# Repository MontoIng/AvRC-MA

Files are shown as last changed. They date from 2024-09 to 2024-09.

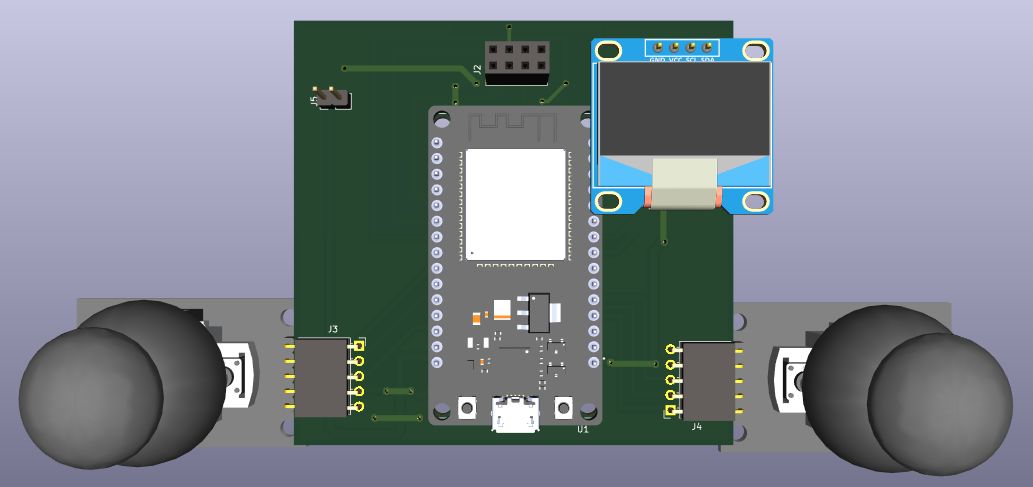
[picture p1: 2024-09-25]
PCBs/Imágenes (KiCad)/Control/Diseño PCB Final (3D - Lado 1).png

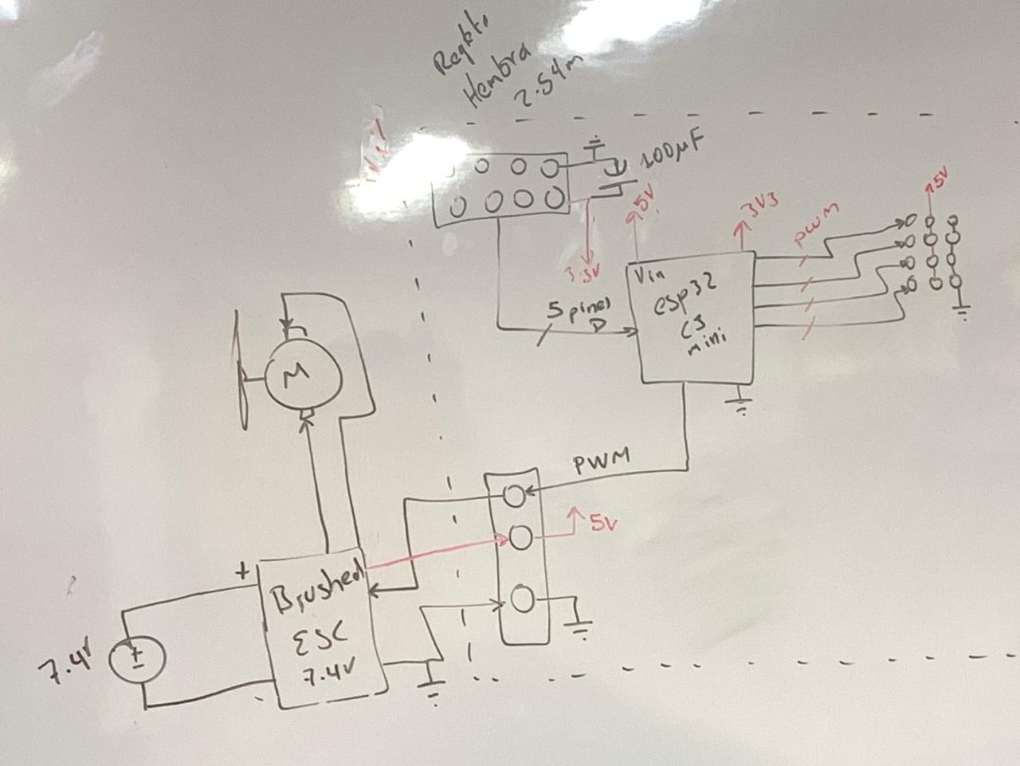
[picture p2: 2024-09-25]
Diseño (muestras)/Diseño prototipado.jpeg

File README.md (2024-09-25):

# AvRC-MA
Avión RC - Monitoreo Ambiental
- En este proyecto se realizó un avión RC (Radio - Control) capaz de tomar datos de temperatura, presión y humedad.
(Santiago Montoya M.)
- Se subió cada codificación usada y creada en la realización del proyecto.
  Siendo asi estos: - Código del control.
                    - Código del Avión.
                    - Código para calibrar el motor.
                    - Librería BME280.
- Se organizó por carpeta los códigos, diseños (muestras - evidencias), documentos y PCBs.
- Se subieron los documentos respectivos a las carpetas.

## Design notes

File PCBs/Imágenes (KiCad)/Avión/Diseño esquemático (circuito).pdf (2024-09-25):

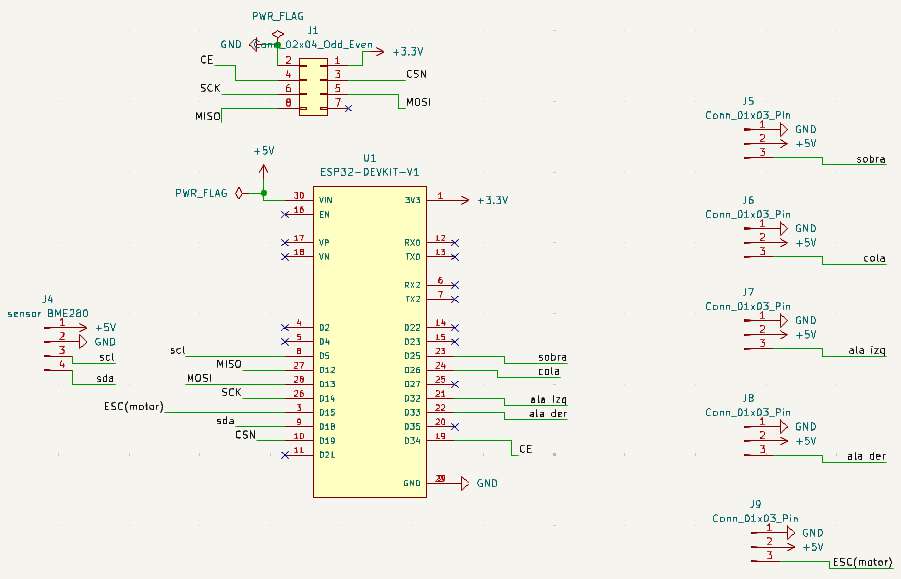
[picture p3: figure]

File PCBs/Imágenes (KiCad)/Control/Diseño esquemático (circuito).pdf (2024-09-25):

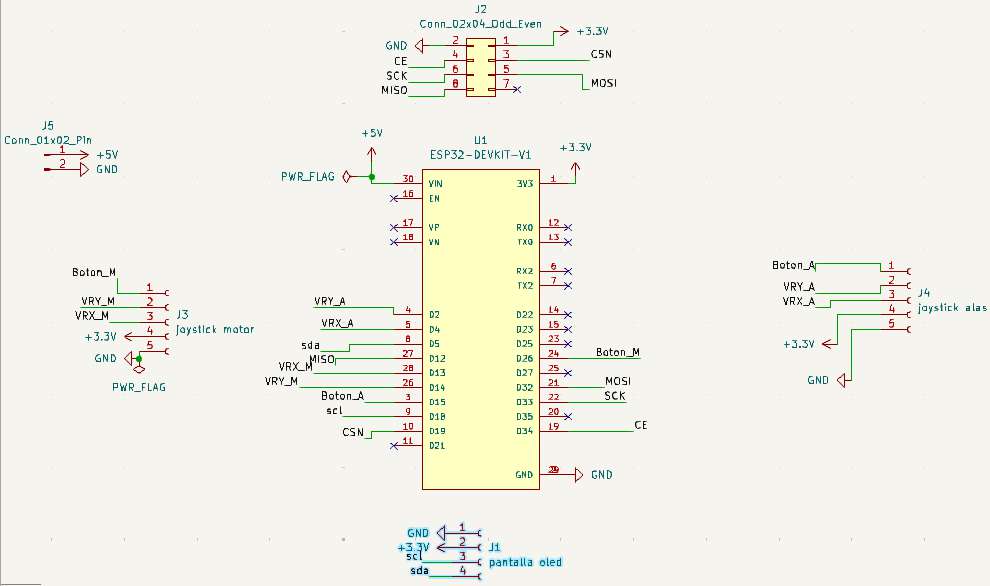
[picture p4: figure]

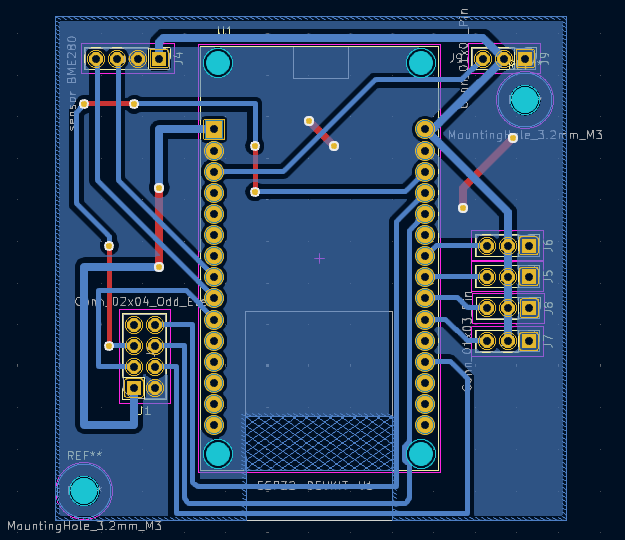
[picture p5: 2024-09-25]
PCBs/Imágenes (KiCad)/Avión/Diseño de PCB (ruteo).png

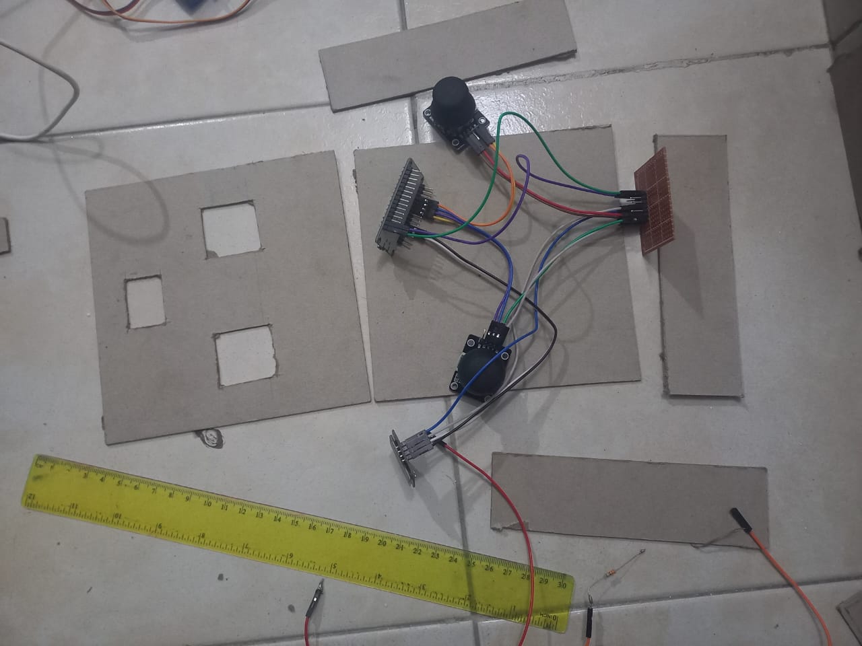
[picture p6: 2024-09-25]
Diseño (muestras)/Diseño (corte).jpeg

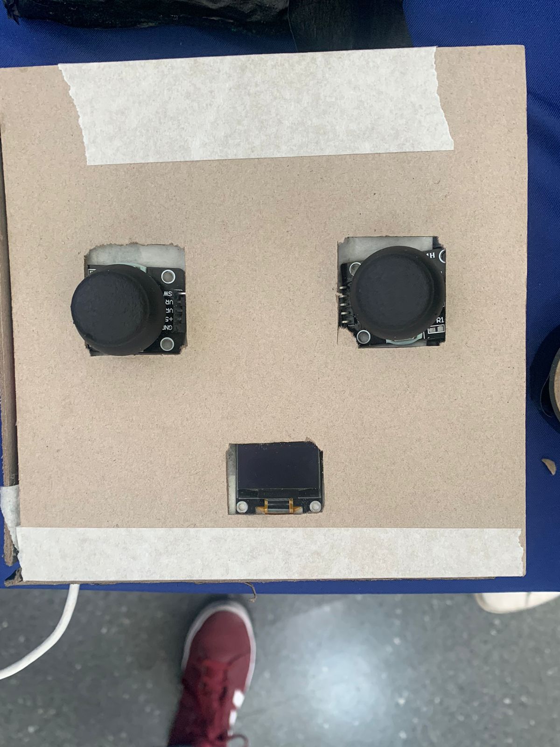
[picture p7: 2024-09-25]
Diseño (muestras)/Diseño control.jpeg

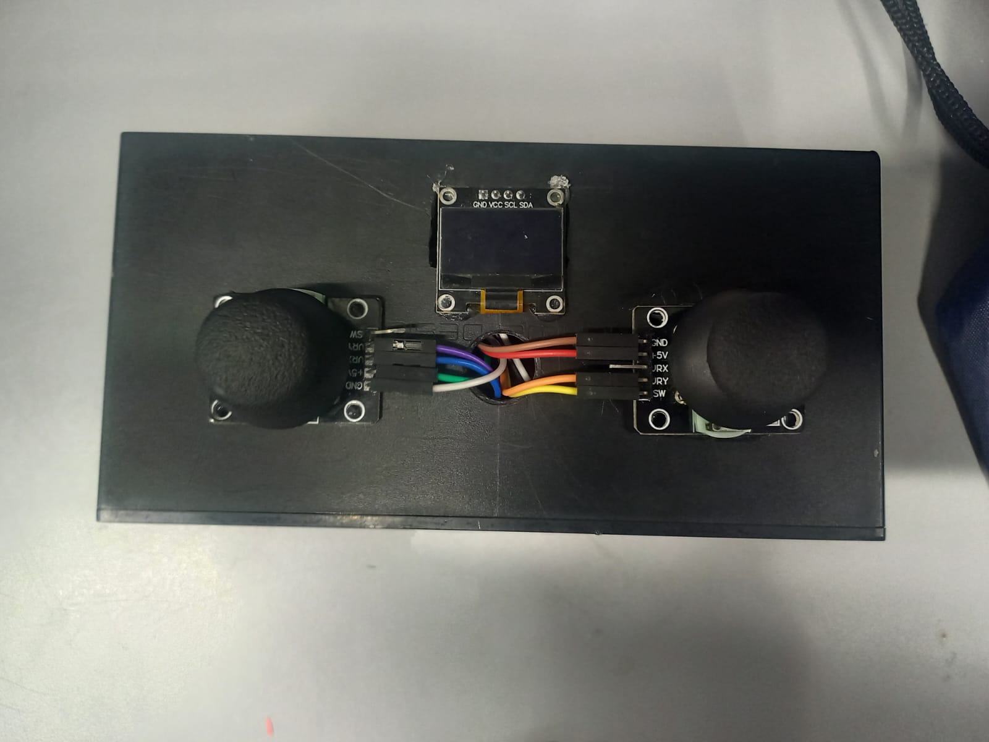
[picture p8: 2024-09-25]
Diseño (muestras)/Diseño control (final).jpeg

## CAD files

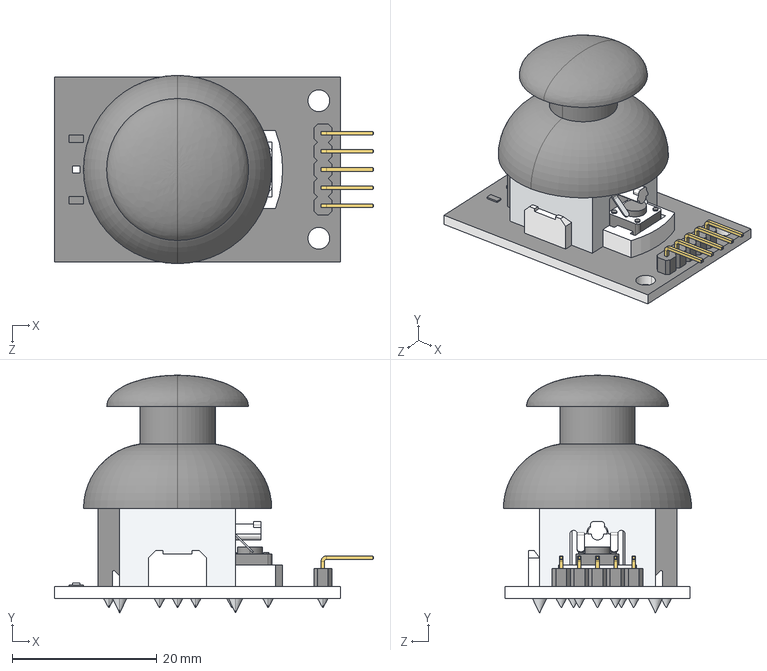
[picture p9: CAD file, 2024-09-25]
PCBs/avion/pcb control/librerias/joystick-module-3.snapshot.1/Joystick.STEP
44.0 x 32.8 x 26.0 mm

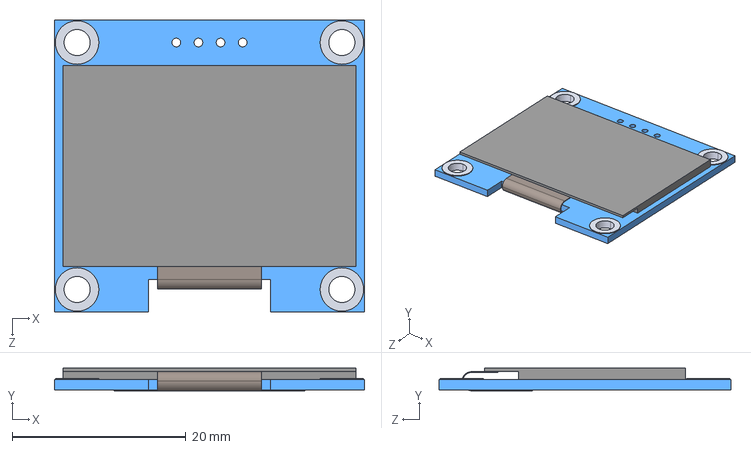
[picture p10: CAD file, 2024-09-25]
PCBs/avion/pcb control/librerias/oled.STEP
35.6 x 2.60 x 33.6 mm

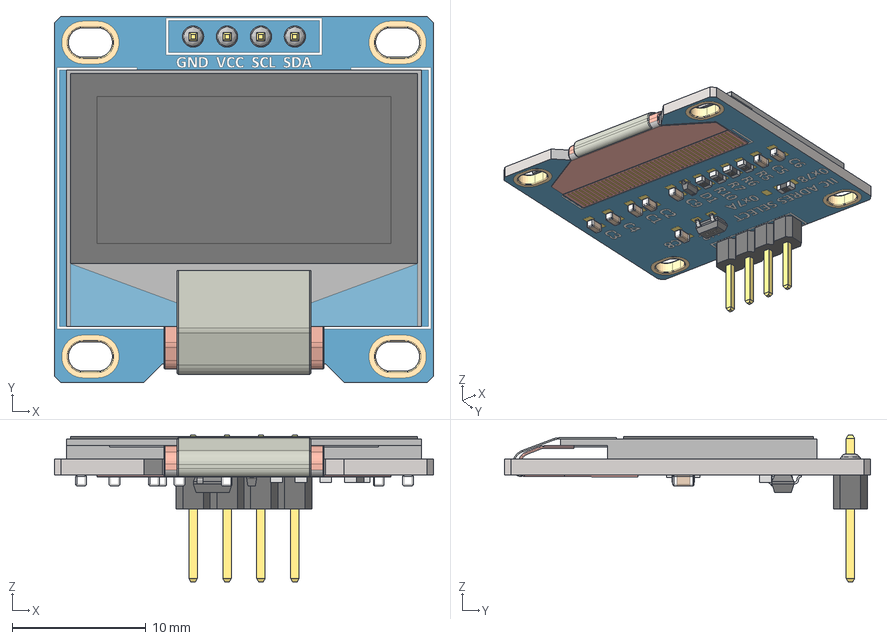
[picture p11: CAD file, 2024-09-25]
PCBs/avion/pcb control/librerias/Pantalla OLED 0.96'' 128x64.stp
28.4 x 27.4 x 11.0 mm
SOT-23_TOR
RES_CR16_MTK_1 x 4
RES_CR16_MTK
SOD323F_DIO

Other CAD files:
PCBs/avion/pcb control/librerias/joystick-module-3.snapshot.1/Joystick.SLDPRT

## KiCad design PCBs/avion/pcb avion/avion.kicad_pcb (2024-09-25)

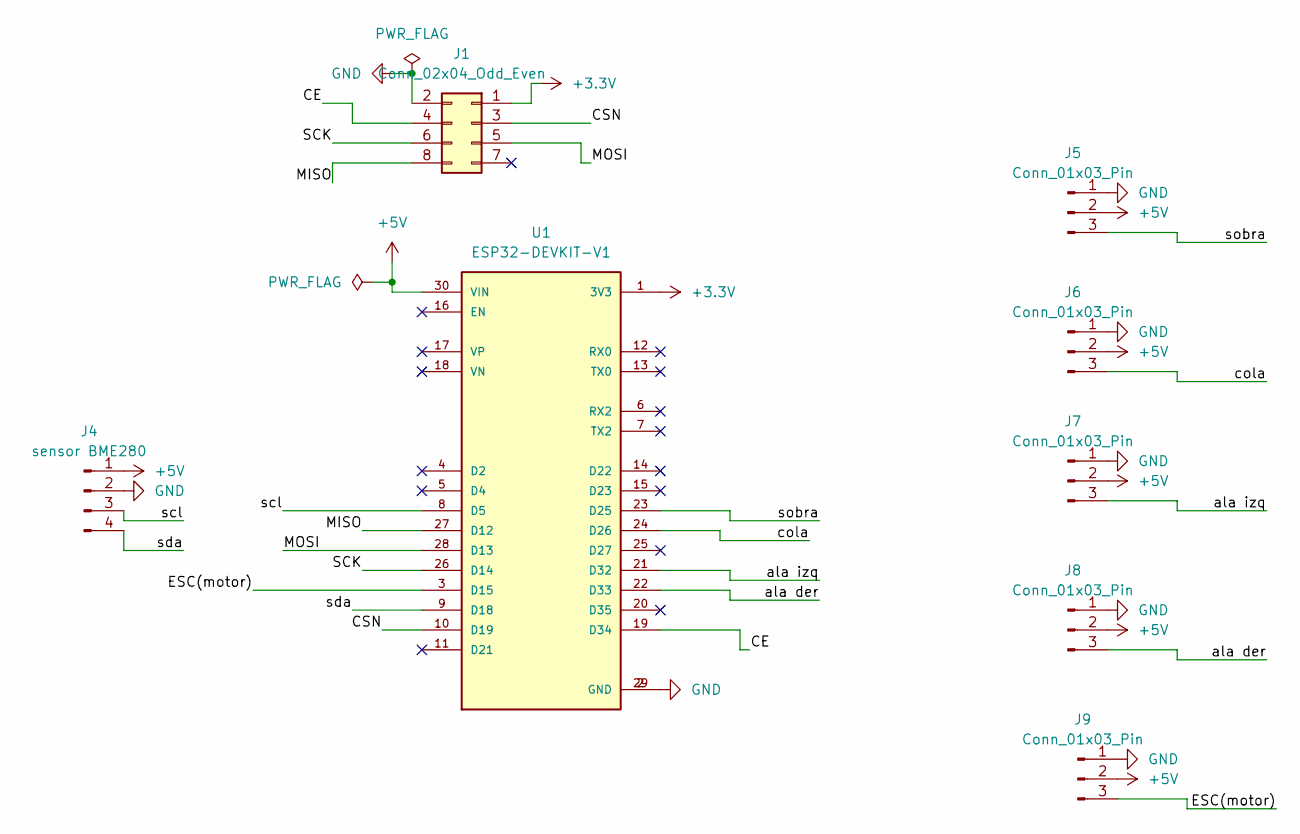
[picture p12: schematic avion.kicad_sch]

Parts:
J1: Conn_02x04_Odd_Even; PinSocket_2x04_P2.54mm_Vertical
J4: sensor BME280; PinHeader_1x04_P2.54mm_Vertical
J5, J6, J7, J8, J9: Conn_01x03_Pin; PinHeader_1x03_P2.54mm_Vertical
U1: ESP32-DEVKIT-V1; MODULE_ESP32_DEVKIT_V1; PARTREV N/A

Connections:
+3.3V: J1.1, U1.1 (3V3)
+5V: J4.1, J5.2, J6.2, J7.2, J8.2, J9.2, U1.30 (VIN)
/CE: J1.4, U1.19 (D34)
/CSN: J1.3, U1.10 (D19)
/ESC(motor): J9.3, U1.3 (D15)
/MISO: J1.8, U1.27 (D12)
/MOSI: J1.5, U1.28 (D13)
/SCK: J1.6, U1.26 (D14)
/ala der: J8.3, U1.22 (D33)
/ala izq: J7.3, U1.21 (D32)
/cola: J6.3, U1.24 (D26)
/scl: J4.3, U1.8 (D5)
/sda: J4.4, U1.9 (D18)
/sobra: J5.3, U1.23 (D25)
GND: J1.2, J4.2, J5.1, J6.1, J7.1, J8.1, J9.1, U1.2 (GND), U1.29 (GND)

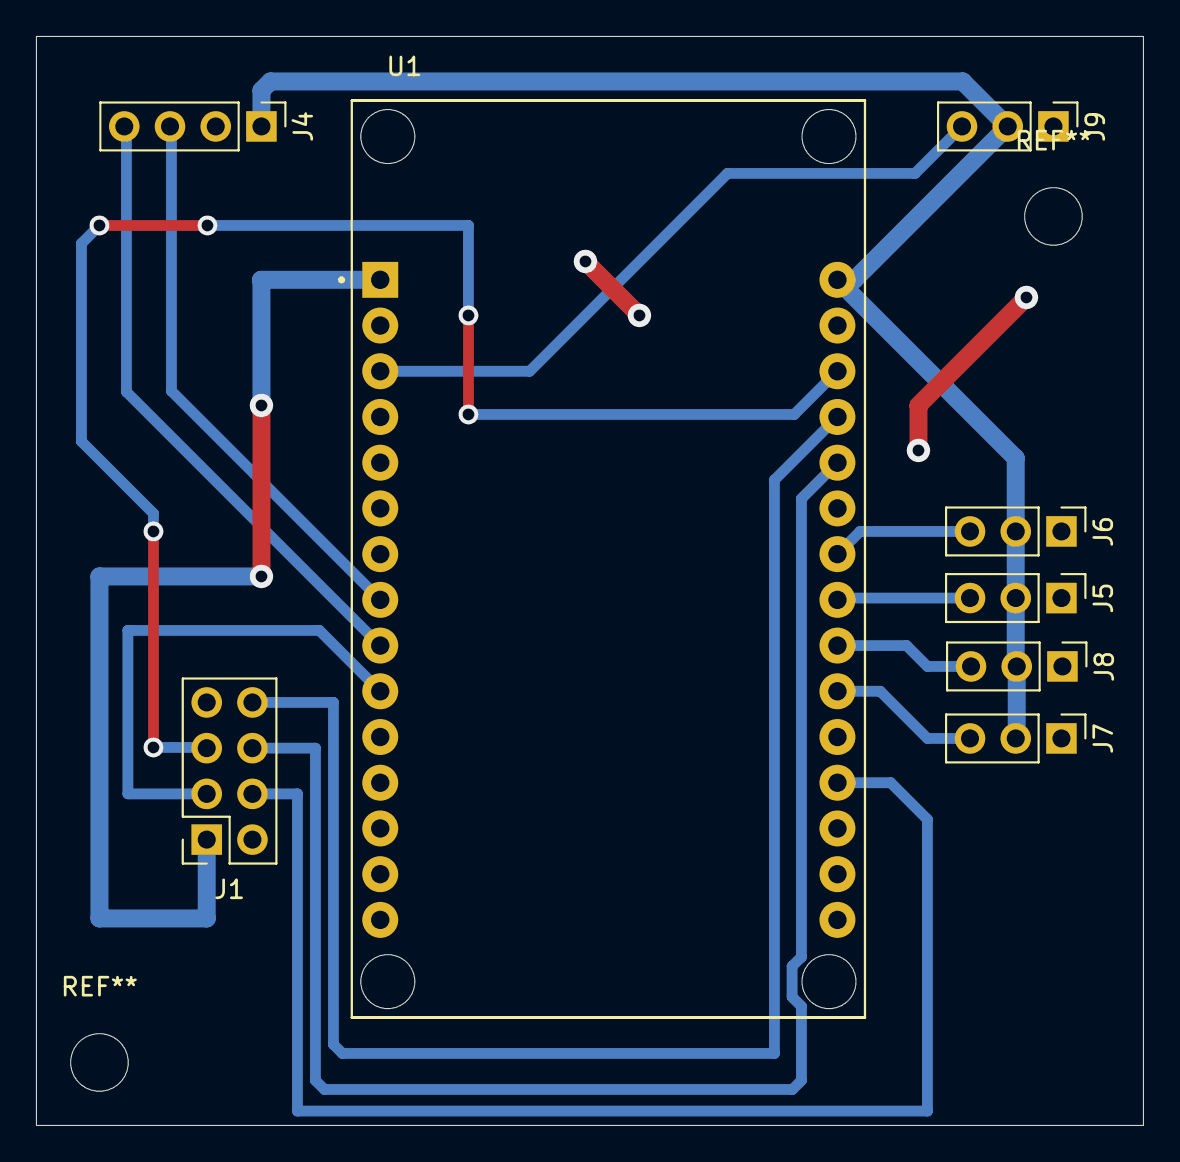
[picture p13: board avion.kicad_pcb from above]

Board: 2 copper layers, 61.5 x 60.5 mm, 8 parts (0 on the bottom side), 15 nets.

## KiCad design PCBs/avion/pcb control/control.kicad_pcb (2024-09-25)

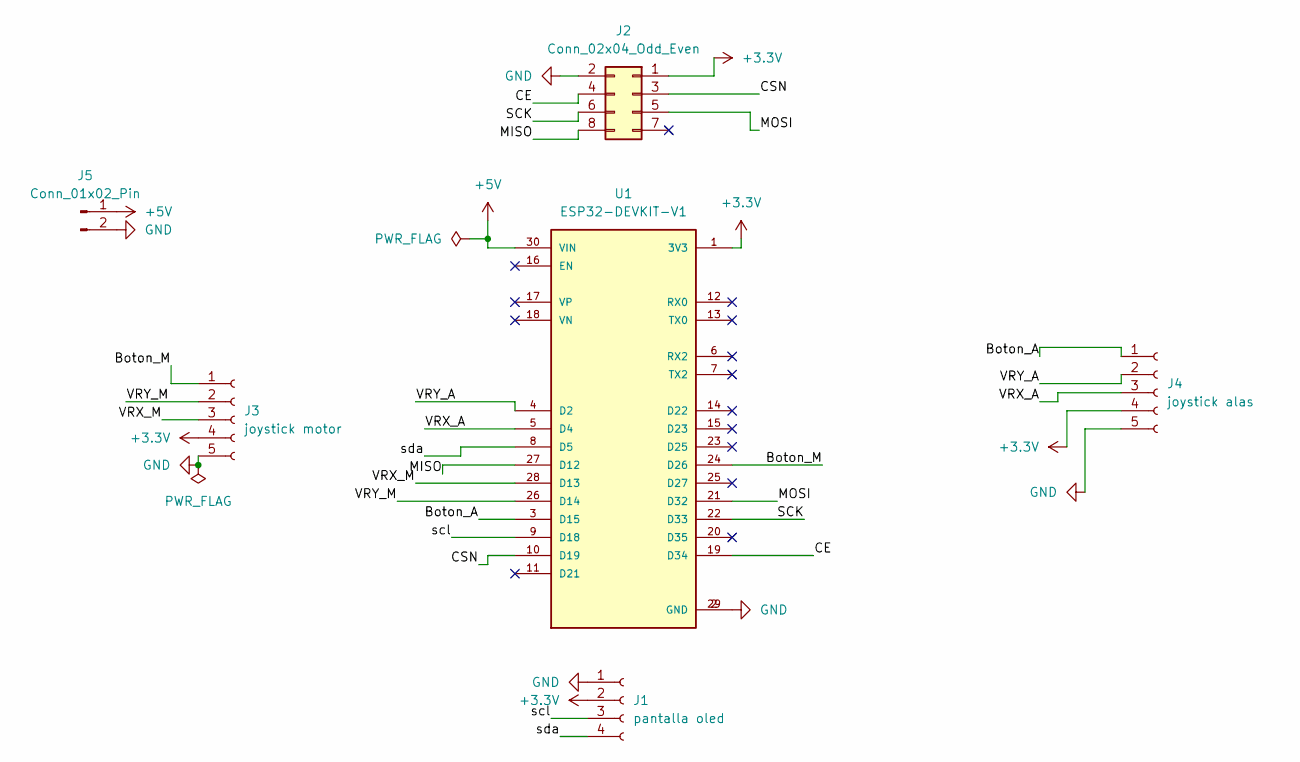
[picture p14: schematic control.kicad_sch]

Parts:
J1: pantalla oled; PinSocket_1x04_P2.54mm_Vertical
J2: Conn_02x04_Odd_Even; PinSocket_2x04_P2.54mm_Vertical
J3: joystick motor; PinSocket_1x05_P2.54mm_Horizontal
J4: joystick alas; PinSocket_1x05_P2.54mm_Horizontal
J5: Conn_01x02_Pin; PinHeader_1x02_P2.54mm_Vertical
U1: ESP32-DEVKIT-V1; MODULE_ESP32_DEVKIT_V1; PARTREV N/A

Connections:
+3.3V: J1.2, J2.1, J3.4, J4.4, U1.1 (3V3)
+5V: J5.1, U1.30 (VIN)
/Boton_A: J4.1, U1.3 (D15)
/Boton_M: J3.1, U1.24 (D26)
/CE: J2.4, U1.19 (D34)
/CSN: J2.3, U1.10 (D19)
/MISO: J2.8, U1.27 (D12)
/MOSI: J2.5, U1.21 (D32)
/SCK: J2.6, U1.22 (D33)
/VRX_A: J4.3, U1.5 (D4)
/VRX_M: J3.3, U1.28 (D13)
/VRY_A: J4.2, U1.4 (D2)
/VRY_M: J3.2, U1.26 (D14)
/scl: J1.3, U1.9 (D18)
/sda: J1.4, U1.8 (D5)
GND: J1.1, J2.2, J3.5, J4.5, J5.2, U1.2 (GND), U1.29 (GND)

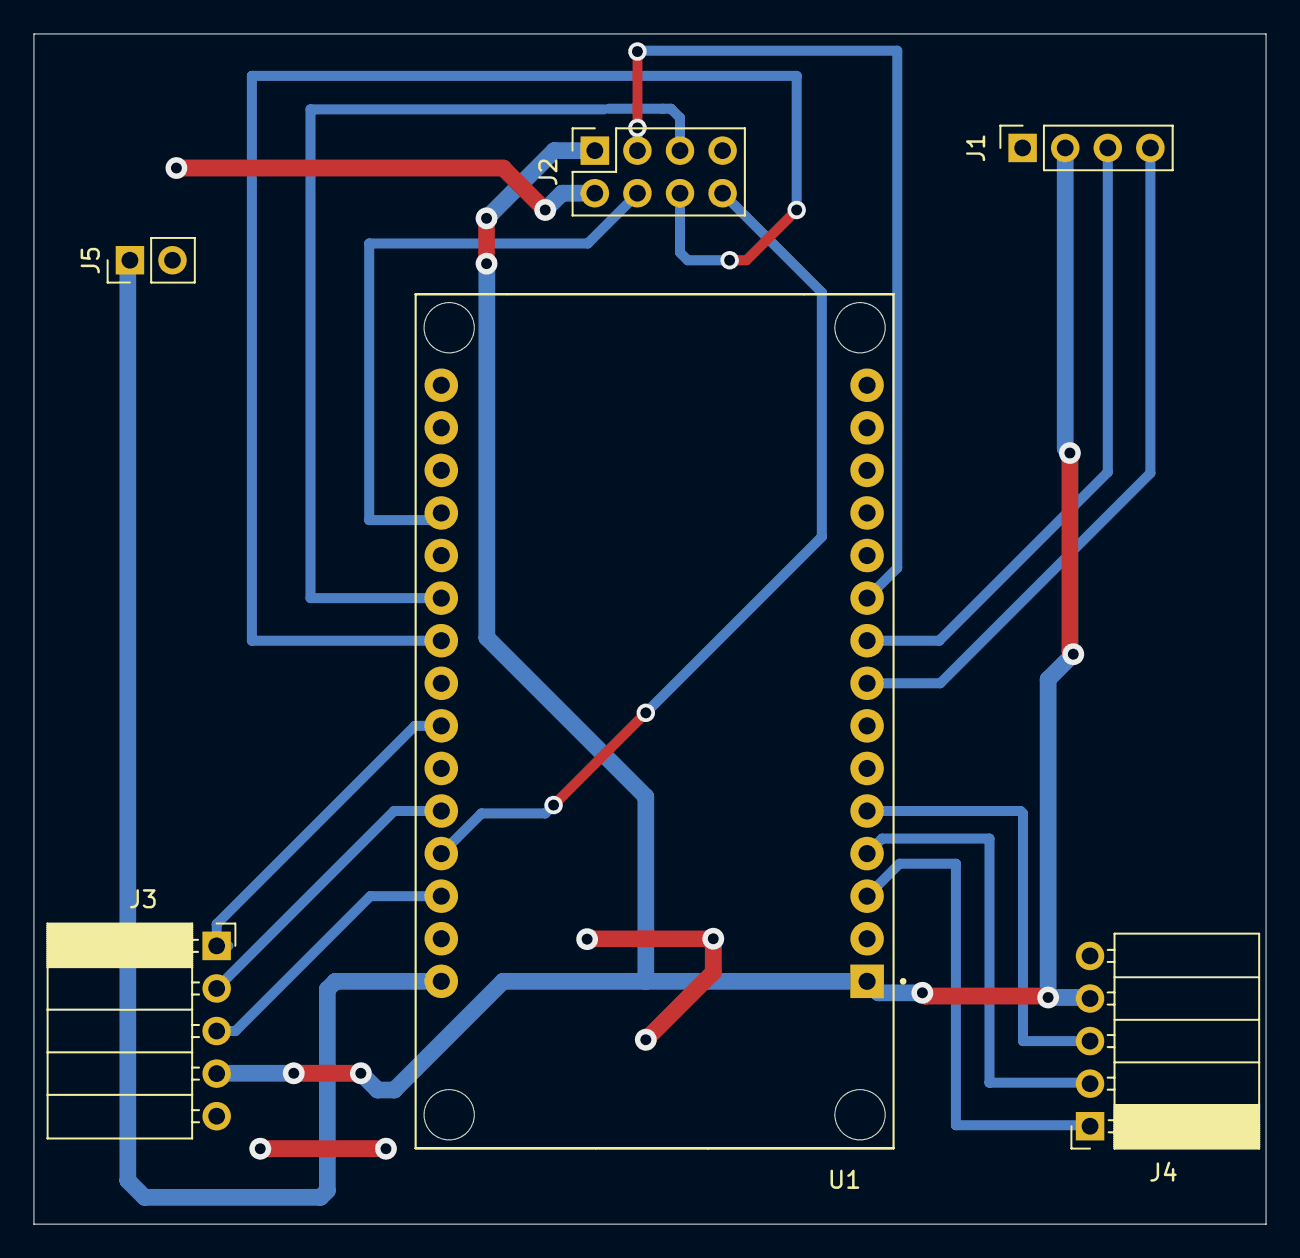
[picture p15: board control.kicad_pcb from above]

Board: 2 copper layers, 73.5 x 71.0 mm, 6 parts (0 on the bottom side), 16 nets.

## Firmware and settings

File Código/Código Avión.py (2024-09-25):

import network
import socket
import struct
from machine import Pin, ADC, I2C, PWM
import time
import bme280



#servomotor
servo_pin1 = Pin(32)
s_izquierda = PWM(servo_pin1, freq=50)
servo_pin2 = Pin(26)
s_derecha = PWM(servo_pin2, freq=50)
servo_pin3 = Pin(25)
s_cola = PWM(servo_pin3, freq=50)
motor_pin = Pin(15)
motor = PWM(motor_pin, freq=50)


#SENSOR BME280
ltemp = []
lhum = []
lpress = []


i2c_sensor = I2C(1, scl=Pin(5), sda=Pin(18))  # Ajusta los pines SCL y SDA según tu configuración
bme = bme280.BME280(i2c=i2c_sensor)

# Configuración de la red Wi-Fi
#Usurio y contraseña en cuestión

def mover_servo(servo, angulo):
    # Asegurarse de que el ángulo esté en el rango permitido
    if angulo < 0:
        angulo = 0
    elif angulo > 200:
        angulo = 200
    
    # Convertir el ángulo a un rango de ciclo de trabajo
    min_pulse = 1000  # Valor mínimo del pulso (us)
    max_pulse = 2000  # Valor máximo del pulso (us)
    pulse_width = min_pulse + (angulo / 180) * (max_pulse - min_pulse)
    
    # Convertir a ciclo de trabajo de 16 bits (0-65535)
    duty = int((pulse_width / 20000) * 65535)
    servo.duty_u16(duty)
    
def set_angle(angle):
    velocidad = 40 + (angle / 180) * 115  # Mapeo de ángulo a duty cycle
    motor.duty(int(velocidad))
    

sta = network.WLAN(network.STA_IF)
sta.active(True)
sta.connect(ssid, password)


while not sta.isconnected():
    pass

print('Conectado. IP:', sta.ifconfig()[0])

# Configuración del puerto para recibir datos
server_port = 8081
server_socket = socket.socket()
server_socket.bind(('0.0.0.0', server_port))
server_socket.listen(1)
server_socket.settimeout(5)  # Tiempo de espera de 5 segundos


# Configuración para enviar datos al ESP32 A
client_ip = '192.168.251.108'  # Reemplaza con la IP del ESP32 A
client_port = 8080


while True:
    start_time = time.time()
    connected = False
    print("Esperando conexión...")

    # Esperar una conexión por un tiempo máximo de 5 segundos
    while not connected:
        if time.time() - start_time > 5:  # Tiempo de espera de 5 segundos
            print("Tiempo de espera alcanzado, intentando de nuevo...")
            break
        try:
            cl, addr = server_socket.accept()  # Intentar aceptar la conexión
            connected = True
            print('Cliente conectado desde', addr)
        except OSError as e:
            pass  # No se ha establecido una conexión aún, continuar esperando

    if connected:
        while True:
            data = cl.recv(8)  # Recibir datos
            if not data:
                break
            x1, y1, x2, y2 = struct.unpack('HHHH', data)
            #print("Recibido de ESP32 A - motor:", x1, "alas:", y1, "cola:", x2, "boton:", y2)
            
            #control de los servos de las alas
            if y1 > 3000:
                mover_servo(s_izquierda, 200)
                mover_servo(s_derecha, 10)
            elif y1 < 1200:
                mover_servo(s_izquierda, 10)
                mover_servo(s_derecha, 200)
            else:
                mover_servo(s_izquierda, 10)
                mover_servo(s_derecha, 10)
                
            #control de los servos de la cola
            if x2 > 3000:
                mover_servo(s_cola, 190)
            elif x2 < 1200:
                mover_servo(s_cola, 0)
            #control velocidad del motor
            if x1>2500:
                set_angle(40)
            else:
                set_angle(0)

            cl.send(b"Datos recibidos")

        cl.close()

    # Enviar datos al ESP32 A
    s = socket.socket()
    try:
        s.connect((client_ip, client_port))
        # Leer los valores del sensor BME280
        temperature, pressure, humidity = bme.read_compensated_data()
        
        # Convertir los datos a valores legibles
        temperature //= 100  # Temperatura en grados Celsius
        pressure //= 100  # Presión en hectopascales (hPa)
        humidity //= 1024# Humedad relativa en porcentaje
        print(temperature, pressure,humidity)

        # Empaquetar los datos en un formato binario
        datos = struct.pack('fff', temperature, pressure,humidity)
        s.send(datos)
        
        
        response = s.recv(1024)
        print('Respuesta del servidor:', response)
        
    except OSError as e:
        print("Error de conexión:", e)
        
    finally:
        s.close()

    #time.sleep(0.5)

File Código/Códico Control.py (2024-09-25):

import network
import socket
import struct
from machine import Pin, ADC, I2C
import ssd1306
import time

#pantalla oled
i2c_oled = I2C(scl=Pin(12), sda=Pin(14))  # Ajusta los pines SCL y SDA según tu configuración

oled_width = 128
oled_height = 64
oled = ssd1306.SSD1306_I2C(oled_width, oled_height, i2c_oled)

# Configuración de los pines y los joysticks
joystick_x1 = ADC(Pin(34))  # Pin analógico para el eje X del primer joystick
joystick_y1 = ADC(Pin(35))  # Pin analógico para el eje Y del primer joystick
joystick_x2 = ADC(Pin(32))  # Pin analógico para el eje X del segundo joystick
sw = Pin(33, Pin.IN, Pin.PULL_UP)

joystick_x1.atten(ADC.ATTN_11DB)
joystick_y1.atten(ADC.ATTN_11DB)
joystick_x2.atten(ADC.ATTN_11DB)


# Configuración de la red Wi-Fi
#ssid = 'HONOR X8'
#password = 'Jorgentas231'
#ssid = 'Movistar'
#password = '97865432'
#ssid = 'Galaxy'
#password = 'Sebastian123'
ssid = 'FAMILIA CORTES'
password = 'marcedigu36'

sta = network.WLAN(network.STA_IF)
sta.active(True)
sta.connect(ssid, password)

while not sta.isconnected():
    pass

print('Conectado. IP:', sta.ifconfig()[0])

# Configuración del puerto para recibir datos
server_port = 8080
server_socket = socket.socket()
server_socket.bind(('0.0.0.0', server_port))
server_socket.listen(1)
server_socket.settimeout(5)  # Tiempo de espera de 5 segundos


# Configuración para enviar datos al ESP32 B
client_ip = '192.168.20.65'  # Reemplaza con la IP del ESP32 B
client_port = 8081

def datos_oled(var1, var2, var3):
    oled.fill(0)
    oled.text("temp:", 0, 0)
    oled.text("C", 90, 0)
    oled.text(str(var1), 50, 0)
    oled.text("hum:", 0, 20)
    oled.text(str(var2), 40, 20)
    oled.text("%", 70, 20)
    oled.text("press:", 0, 40)
    oled.text(str(var3), 50, 40)
    oled.show()
    
def limpiar():
    oled.fill(0)
    oled.show()

vacia = True

while True:
    start_time = time.time()
    connected = False
    print("Esperando conexión...")

    # Esperar una conexión por un tiempo máximo de 5 segundos
    while not connected:
        if time.time() - start_time > 5:  # Tiempo de espera de 5 segundos
            print("Tiempo de espera alcanzado, intentando de nuevo...")
            break
        try:
            cl, addr = server_socket.accept()  # Intentar aceptar la conexión
            connected = True
            print('Cliente conectado desde', addr)
        except OSError as e:
            pass  # No se ha establecido una conexión aún, continuar esperando

    if connected:
        while True:
            data = cl.recv(12)  # Recibir datos
            if not data:
                break
            temperatura, presion, humedad = struct.unpack('fff', data)
            print("Recibido de ESP32 B - temperatura", temperatura, "humedad", humedad, "presion", presion)
            cl.send(b"Datos recibidos")
        cl.close()


    # Enviar datos al ESP32 B
    s = socket.socket()
    try:
        s.connect((client_ip, client_port))
        # Leer los valores de los joysticks
        motor = joystick_x1.read()
        alas = joystick_y1.read()
        cola = joystick_x2.read()
        boton = sw.value()
        
        
        # Empaquetar los datos en un formato binario
        datos = struct.pack('HHHH', motor, alas, cola, boton)
        s.send(datos)
        
        response = s.recv(1024)
        print('Respuesta del servidor:', response)
    except OSError as e:
        print("Error de conexión:", e)
    finally:
        s.close()

    if sw.value() == 0:
        if vacia:
            datos_oled(temperatura, humedad, presion)
            vacia = False
        else:
            limpiar()
            vacia = True
        
    #time.sleep(0.5)

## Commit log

2024-09-18 Actualización README
    Se definió la función del proyecto
2024-09-25 Update Files
    Se añaden en carpetas:
    - Documentos.
    - PCBs.
    - Diseños (muestras - evidencias).
2024-09-25 Update PCBs
    Se añade proyecto KiCad
    [Joystick.SLDPRT, Joystick.STEP, Pantalla OLED 0.96'' 128x64.stp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]
2024-09-25 Update Documents
    Se suben imágenes restantes a la carpeta.
2024-09-25 Update Images
    Se actualizan imágenes/documentos completos de las PCBs y su creación en KiCad.
